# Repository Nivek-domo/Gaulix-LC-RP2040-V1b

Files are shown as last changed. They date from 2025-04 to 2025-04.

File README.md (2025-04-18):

Version : Bêta. Elle est opérationnelle, mais proposée à titre de tests pour ses acquéreurs, pour le moment …

Résumé du projet

Ce projet vise à concevoir une carte basée sur le RP2040 LoRa, inspirée du modèle Waveshare, mais optimisée pour des performances accrues et une meilleure stabilité. L’objectif est d’offrir une solution modulaire et performante pour des applications LoRa à faible coût.

Caractéristiques principales :

Microcontrôleur : RP2040 et mémoire additionnel
Module LoRa : Version optimisée avec un véritable étage radio, incluant un TCXO pour une meilleure stabilité en fréquence. Avec le Ebyte e22-900m30s
Puissance de sortie : Jusqu’à 30dBm (1W), pouvant être bridée à 27dBm (0,5W) pour rester dans la légalité.
Alimentation :
Entrée 5V via USB-C (H13)
Possibilité d’alimentation via batterie lithium (H14) pour une autonomie accrue.
Interfaces accessibles :
I2C pour capteurs divers
UART pour GPS ou autres modules de communication
SPI pour Ethernet (W5500) ou écrans e-paper
GPIO analogiques et numériques
Firmware : Compatible avec un firmware custom pour maximiser les performances et les options de configuration.
Options d’alimentation autonome :

Panneau solaire + régulateur de tension à 5 V.
Batterie lithium avec gestion de charge intégrée.
Options de connectivité réseau :

Connexion directe au smartphone via OTG USB-C
Extension réseau via module Ethernet W5500
Choix du module LoRa : E22-900M30S

Cette carte est idéale pour une installation en point haut et un usage longue durée sans maintenance fréquente. Son coût maîtrisé et sa modularité en font un choix optimal pour les expérimentateurs LoRa et les radioamateurs souhaitant un réseau performant et fiable.

Ses caractéristiques:

Microprocesseur	RP2040
Partie LoRa	
Module	Ebyte 850~930 MHz E22-900M30S
Puissance max	30 dBm
Sensibilité	-150 dBm
TCXO	Oui
Alimentation de la carte	
Par port USB-C	Oui
Directe	5 Volts (5,5 Volts Max) Bornier à Vis
Batterie	un élément lithium 2500mA/H Bornier à Vis

Connectivité

Wifi	Non
Bluetooth	Non
USB	Oui type C
UART 1	Disponible sur broche Dupont
UART 2	Disponible sur broche Dupont
I2C	Disponible sur broche Dupont
SPI	Disponible sur broche Dupont
GPIO Disponible	3 x entrée Analogique
2 x entrée ou sortie numérique
Ethernet	Compatible carte W5500 sur le bus SPI à ajouter.
Fonctionnalités

Alimentation	Entrée fixe 5 Volts // USB C
Gestion panneau solaire	Non
Gestion batterie	Chargeur simple élément
POE	En développement
Firmware

Meshtatic	Version Bêta officielle en cours	Custom

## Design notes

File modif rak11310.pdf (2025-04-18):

Fichier
scr/graphics/img/icon.xbm

#ifndef USERPREFS_HAS_SPLASH #define icon_width 50

#define icon_height 28

static uint8_t icon_bits[] = {
0x0A, 0x00, 0x00, 0x00, 0x00, 0x00, 0x00, 0x40, 0x00, 0x00, 0x00, 0x00, 0x00, 0x00, 0x01, 0x38, 0x00, 0xFC, 0xFF, 0x03, 0x00, 0x70, 0x00, 0xFE, 0xFF, 0xFF, 0x7F, 0x00, 0x08, 0x05, 0xFE, 0xFF, 0xFF, 0x7F, 0x00, 0x08, 0xC0, 0xFF, 0xDF, 0x80, 0x7F, 0x00, 0x00, 0x00, 0xF0, 0x00, 0x02, 0x00, 0x00, 0x30, 0x00, 0x00, 0x70, 0x0C, 0x00, 0x00, 0x40, 0x00, 0x00, 0x00, 0x12, 0x00, 0x00, 0x80, 0x18, 0x00, 0x00, 0x00, 0x00, 0x00, 0x00, 0x01, 0x00, 0x00, 0x40, 0x00, 0x00, 0x00, 0x03, 0x00, 0x00, 0x00, 0x00, 0x00, 0x00, 0x0F, 0x00, 0x00, 0x80, 0x01, 0x00, 0x80, 0xFF, 0x00, 0x00, 0x00, 0xFF, 0x00, 0x80, 0x1F, 0x1C, 0x00, 0x00, 0xFF, 0x00, 0x00, 0x3F, 0x00, 0x04, 0x80, 0xFF, 0x00, 0x00, 0xFF, 0x00, 0x00, 0x80, 0xFE, 0x00, 0x00, 0xFF, 0x01, 0x00, 0x40, 0xFE, 0x00, 0x00, 0xFE, 0x0F, 0x00, 0x20, 0xFE, 0x00, 0x00, 0xFC, 0x0F, 0xFA, 0x01, 0xFE, 0x00, 0x00, 0xF8, 0x3F, 0x00, 0x00, 0xFE, 0x00, 0x00, 0xE0, 0xFF, 0x01, 0x00, 0xFE, 0x00, 0x00, 0xC0, 0xFF, 0x1F, 0xC0, 0xFF, 0x00, 0x00, 0x00, 0xFE, 0xFF, 0xFF, 0xFF, 0x00, 0x00, 0x00, 0xE0, 0xFF, 0xFF, 0x7F, 0x00, 0x00, 0x00, 0x00, 0xFC, 0xFF, 0x03, 0x00, 0x00, 0x00, 0x00, 0x00, 0x00, 0x00, 0x00, 0x00, 0x00, 0x00, 0x00, 0x00, 0x00, 0x00, };
#endif

scr/graphics/Screen.cpp

ligne 58

#if HAS_ETHERNET

#include "mesh/eth/ethClient.h" #endif

ligne 169
display->setFont(FONT_MEDIUM); display->setTextAlignment(TEXT_ALIGN_LEFT);
const char *title = "gaulix.fr";
display->drawString(x + getStringCenteredX(title), y + SCREEN_HEIGHT -FONT_HEIGHT_MEDIUM, title);
display->setFont(FONT_SMALL);

ligne 238

#if HAS_ETHERNET

static void drawEthernetFrame(OLEDDisplay *display, OLEDDisplayUiState *state, int16_t x, int16_t y)
{
display->setFont(FONT_SMALL);
display->setTextAlignment(TEXT_ALIGN_LEFT);

if (config.display.displaymode == meshtastic_Config_DisplayConfig_DisplayMode_INVERTED) { display->fillRect(0 + x, 0 + y, x + display->getWidth(), y + FONT_HEIGHT_SMALL); display->setColor(BLACK);
}

display->setColor(WHITE);
// Position verticale ajustée - commence plus haut int16_t y_offset = y + 2; // Réduit l'espace au-dessus // Alignement à gauche (x + petit offset)
int16_t x_offset = x + 2;
// Affichage non centré, aligné à gauche
display->drawString(x_offset, y_offset, "Ethernet Config:");
y_offset += FONT_HEIGHT_SMALL + 2; // Espacement légèrement réduit display->drawString(x_offset, y_offset, "IP: " + Ethernet.localIP().toString()); y_offset += FONT_HEIGHT_SMALL;
display->drawString(x_offset, y_offset, "Mask: " + Ethernet.subnetMask().toString()); y_offset += FONT_HEIGHT_SMALL;
display->drawString(x_offset, y_offset, "GW: " + Ethernet.gatewayIP().toString()); //y_offset += FONT_HEIGHT_SMALL;
//display->drawString(x_offset, y_offset, "DNS: " + Ethernet.dnsServerIP().toString()); }
#endif

ligne 453

snprintf(tempBuf, sizeof(tempBuf), "Critical fault #%d", error_code); display->drawString(0 + x, 0 + y, tempBuf);
display->setTextAlignment(TEXT_ALIGN_LEFT);
display->setFont(FONT_SMALL);
display->drawString(0 + x, FONT_HEIGHT_MEDIUM + y, "For help, please visit \ngaulix.fr"); }

ligne 2215

#if HAS_ETHERNET

if (Ethernet.hardwareStatus() != EthernetNoHardware) { normalFrames[numframes++] = drawEthernetFrame; }
#endif

scr/mesh/RadioInterface.cpp

ligne 48
RDEF(EU_868, 869.4f, 869.65f, 10, 0, 27, false, false, false), //RDEF(EU_868, 869.4f, 869.65f, 10, 0, 33, false, false, false),

scr/mesh/api/serverapi.h
ligne 47
//#if RAK_4631
#if defined(RAK_4631) || defined(RAK11310)

// Track wait time for RAK13800 Ethernet requests int32_t waitTime = 100;
#endif

scr/mesh/eth/ethClient.cpp
ligne 115

#ifdef RAK11310 // Initialize the SPI port ETH_SPI_PORT.setSCK(PIN_SPI0_SCK); ETH_SPI_PORT.setTX(PIN_SPI0_MOSI); ETH_SPI_PORT.setRX(PIN_SPI0_MISO); ETH_SPI_PORT.begin();

#endif

Ethernet.init(ETH_SPI_PORT, PIN_ETHERNET_SS);

uint8_t mac[6];

dans
scr/modules on ajoute 2 fichiers NivekRemoteModule.cpp

#include "NivekRemoteModule.h"

#include "configuration.h"

#include "MeshService.h"

bool NivekRemoteModule::wantPacket(const meshtastic_MeshPacket *p) {
if (MeshService::isTextPayload(p) && p->decoded.payload.size >= 12) { // 9 (Node ID) + 2 (Pin) + 1 (State)
// Récupérer l'ID du nœud en tant que chaîne de caractères
NodeNum nodeID = myNodeInfo.my_node_num;
char nodeIDStr[10]; // Stocke l'ID en tant que string
snprintf(nodeIDStr, sizeof(nodeIDStr), "%u", nodeID); // Convertir en string // Comparer les 9 premiers caractères avec l'ID du nœud
if (strncmp((char*)p->decoded.payload.bytes, nodeIDStr, 9) == 0) {
// Extraire le numéro de sortie (2 caractères après l'ID du nœud)
int pin = ((p->decoded.payload.bytes[9] - '0') * 10) + (p->decoded.payload.bytes[10] -'0');

// Vérifier que la valeur est bien entre 0 et 32
if (pin >= 0 && pin <= 32) {
// Extraire l'état de la sortie (dernier caractère)
bool state = (p->decoded.payload.bytes[11] == '1');

pinMode(pin, OUTPUT);

digitalWrite(pin, state);

// Affichage sur le port série pour debug Serial.print("Commande reçue pour Node "); Serial.print(nodeID);
Serial.print(" : Pin ");
Serial.print(pin);
Serial.print(" -> État "); Serial.println(state ? "ON" : "OFF");

return true;
}
}
}
return false;
}

et NivekRemoteModule.h

#pragma once

#include "SinglePortModule.h"

class NivekRemoteModule : public SinglePortModule
{
public:
NivekRemoteModule() : SinglePortModule("nivekRemote", meshtastic_PortNum_TEXT_MESSAGE_APP) {}

protected:
virtual bool wantPacket(const meshtastic_MeshPacket *p) override; };

et donc dans scr/modules/Modules.cpp
ligne 145

new NivekRemoteModule();
ligne 93

#include "modules/NivekRemoteModule.h"

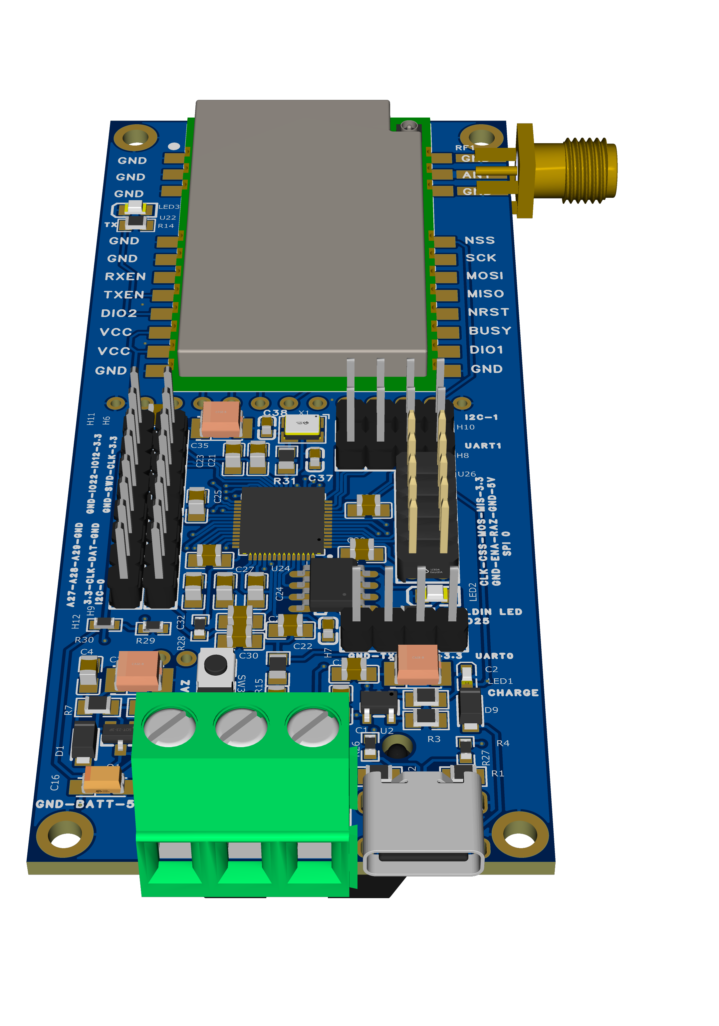
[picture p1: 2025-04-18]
3D_PCB1_2025-04-18.png

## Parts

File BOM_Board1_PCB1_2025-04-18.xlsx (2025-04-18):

No. | Quantity | Comment | Designator | Footprint | Value | Manufacturer Part | Manufacturer | Supplier Part | Supplier
1 | 2 | 1uF | C1,C4 | C0805 | 1uF | CL21B105KBFNNNE | SAMSUNG(三星) | C28323 | LCSC
2 | 3 | 100uF | C2,C3,C35 | CASE-B_3528 | 100uF | TAJB107K006RNJ | Kyocera AVX | C16133 | LCSC
3 | 15 | 100nF | C12,C15,C21,C22,C23,C24,C25,C26,C27,C28,C29,C30,C31,C32,C36 | C0805 | 100nF | CC0805KRX7R9BB104 | YAGEO(国巨) | C49678 | LCSC
4 | 1 | 10uF | C16 | CAP-SMD_L3.2-W1.6-RD-C7171 | 10uF | TAJA106K016RNJ | Kyocera AVX | C7171 | LCSC
5 | 1 | 1uF | C20 | C0603 | 1uF | CL10A105KO8NNNC | SAMSUNG(三星) | C1592 | LCSC
6 | 2 | 15pF | C37,C38 | C0603 | 15pF | CL10C150JB8NNNC | SAMSUNG(三星) | C1644 | LCSC
7 | 3 | MBR140SFT1G | D1,D9,D10 | SOD-123F_L2.8-W1.8-LS3.7-RD |  | MBR140SFT1G | onsemi(安森美) | C43381 | LCSC
8 | 6 | PZ254V-11-04P | H7,H8,H9,H10,H11,H12 | HDR-TH_4P-P2.54-V-M |  | PZ254V-11-04P | XFCN(兴飞) | C2691448 | LCSC
9 | 1 | KT-0603R | LED1 | LED0603-RD |  | KT-0603R | KENTO | C2286 | LCSC
10 | 1 | KT-0805G | LED2 | LED0805-R-RD |  | KT-0805G | KENTO | C2297 | LCSC
11 | 1 | KT-0805B | LED3 | LED0805-R-RD |  | KT-0805B | KENTO | C2293 | LCSC
12 | 1 | WJ500V-5.08-3P | P1 | CONN-TH_3P-P5.00_WJ500V-5.08-3P |  | WJ500V-5.08-3P | KANGNEX(康奈克斯电气) | C72334 | LCSC
13 | 1 | AO3401A | Q1 | SOT-23_L2.9-W1.3-P1.90-LS2.4-BR |  | AO3401A | AOS | C15127 | LCSC
14 | 4 | 4.7kΩ | R1,R2,R13,R14 | R0805 | 4.7kΩ | 0805W8F4701T5E | UNI-ROYAL(厚声) | C17673 | LCSC
15 | 1 | 2.7kΩ | R3 | R0805 | 2.7kΩ | 0805W8F2701T5E | UNI-ROYAL(厚声) | C17530 | LCSC
16 | 3 | 1kΩ | R4,R7,R31 | R0805 | 1kΩ | 0805W8F1001T5E | UNI-ROYAL(厚声) | C17513 | LCSC
17 | 2 | 10kΩ | R8,R15 | R0805 | 10kΩ | 0805W8F1002T5E | UNI-ROYAL(厚声) | C17414 | LCSC
18 | 2 | 27Ω | R26,R27 | R0603 | 27Ω | 0603WAF270JT5E | UNI-ROYAL(厚声) | C25190 | LCSC
19 | 1 | 200Ω | R28 | R0603 | 200Ω | 0603WAF2000T5E | UNI-ROYAL(厚声) | C8218 | LCSC
20 | 1 | 100kΩ | R29 | R0603 | 100kΩ | 0603WAF1003T5E | UNI-ROYAL(厚声) | C25803 | LCSC
21 | 1 | 200kΩ | R30 | R0603 | 200kΩ | 0603WAF2003T5E | UNI-ROYAL(厚声) | C25811 | LCSC
22 | 1 | BWSMA-KE-P001 | RF1 | SMA-SMD_BWSMA-KE-P001 |  | BWSMA-KE-P001 | BAT WIRELESS(蝙蝠无线) | C496550 | LCSC
23 | 2 | TSA343G00D-250J2 | SW3,SW4 | SW-SMD_L4.0-W2.9-P4.15-EH |  | TSA343G00D-250J2 | BRIGHT(博瑞泰) | C354947 | LCSC
24 | 1 | TP4054 | U2 | SOT-23-5_L2.9-W1.6-P0.95-LS2.8-BR |  | TP4054 | JSMSEMI(杰盛微) | C5381776 | LCSC
25 | 1 | E22-900M30S | U22 | WIRELM-SMD_E22-900M30S |  | E22-900M30S | EBYTE(亿佰特) | C411294 | LCSC
26 | 1 | RP2040 | U24 | LQFN-56_L7.0-W7.0-P0.4-EP |  | RP2040 | Raspberry Pi(树莓派) | C2040 | LCSC
27 | 1 | W25Q16JVSNIQ | U25 | SOP-8_L4.9-W3.9-P1.27-LS6.0-BL |  | W25Q16JVSNIQ | WINBOND(华邦) | qspi ss patte 56 sd0 | LCSC
28 | 1 | ZX-PZ2.54-2-5PZZ | U26 | HDR-TH_10P-P2.54-V-M-R2-C5-S2.54 |  | ZX-PZ2.54-2-5PZZ | Megastar(兆星) | C7501276 | LCSC
29 | 1 | AMS1117-3.3 | U27 | SOT-223-4_L6.5-W3.5-P2.30-LS7.0-BR |  | AMS1117-3.3 | UMW(友台半导体) | C347222 | LCSC
30 | 1 | 918-418K2023S40001 | USBC1 | USB-C-SMD_TYPE-C-USB-17 |  | 918-418K2023S40001 | 精拓金 | C167321 | LCSC
31 | 1 | 12MHz | X1 | OSC-SMD_4P-L3.2-W2.5-BL | 12MHz | XL2EL89COI-111YLC-12M | YXC(扬兴晶振) | C5280578 | LCSC

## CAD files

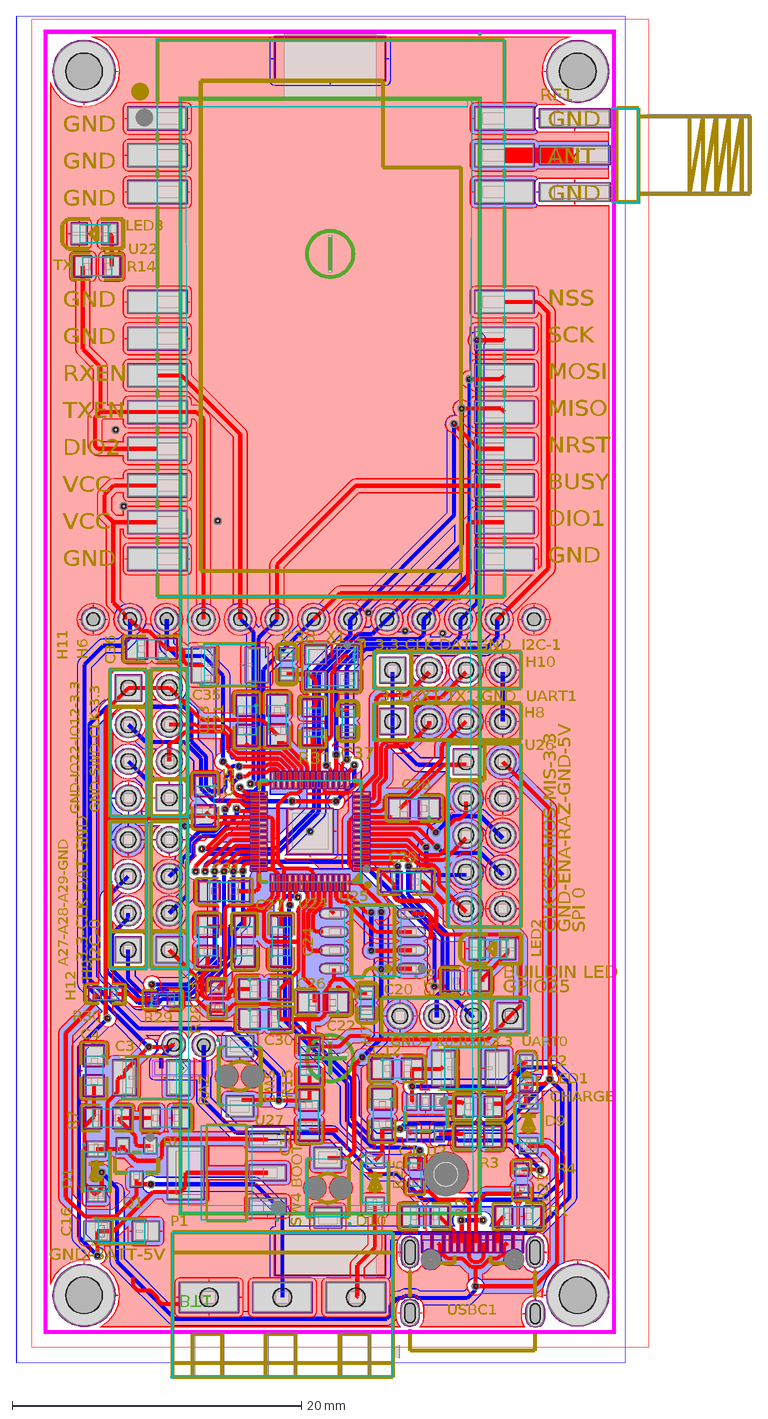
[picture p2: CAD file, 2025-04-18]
DXF_PCB1_2025-04-18_AutoCAD2007.dxf
BT1
GND
ANT
RXEN
TXEN
DIO2
VCC
NSS
SCK
MOSI
MISO
NRST
BUSY
DIO1
3.3-CLK-DAT-GND I2C-1
3.3-RX1-TX1-GND UART1
CLK-CSS-MOS-MIS-3.3
GND-ENA-RAZ-GND-5V
SPI 0
BUILDIN LED
GPIO25
GND-TX0-RX0-3.3 UART0
CHARGE
RAZ
BOOT
TX
GND-IO22-IO12-3.3
GND-SWD-CLK-3.3
3.3-CLK-DAT-GND
I2C-0
A27-A28-A29-GND
GND-BATT-5V
USBC1
R1
R2
D1
U2
D9
C1
C2
Q1
R7
R8
C3
C4
C12
LED2
R13
LED3
R14
C15
R15
R3
R4
LED1
C16
U22
C20
C21
C22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

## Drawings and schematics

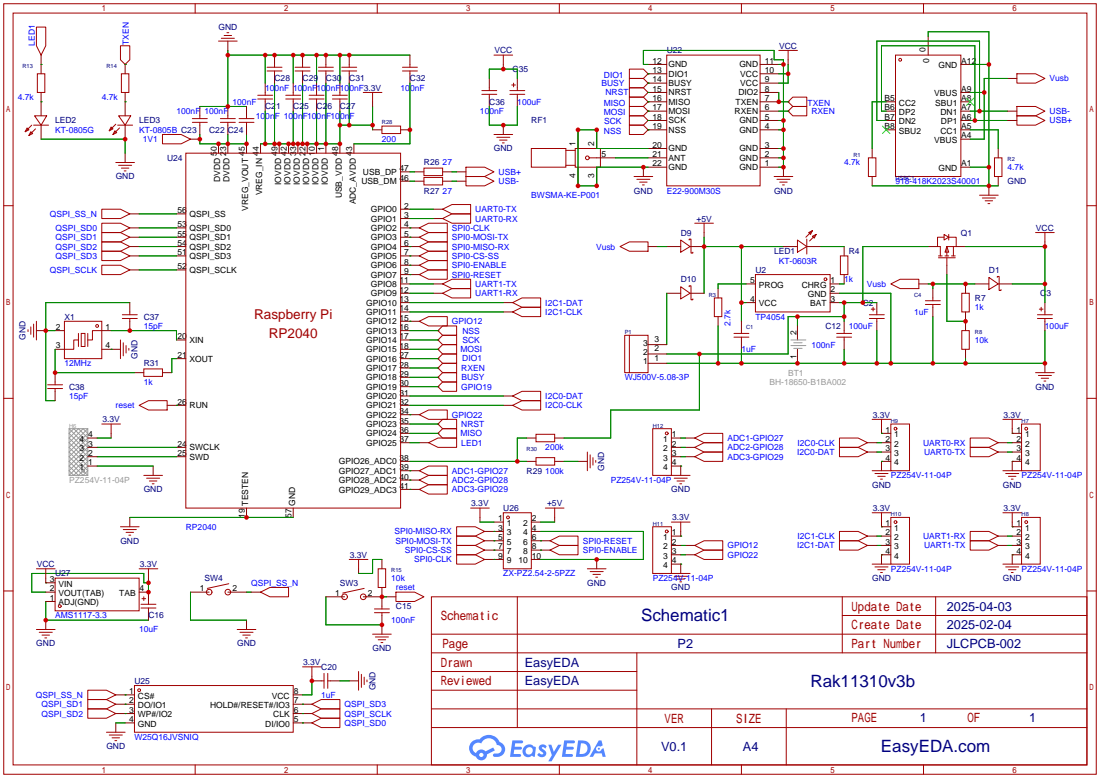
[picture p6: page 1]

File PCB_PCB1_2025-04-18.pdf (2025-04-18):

# GND

# GND

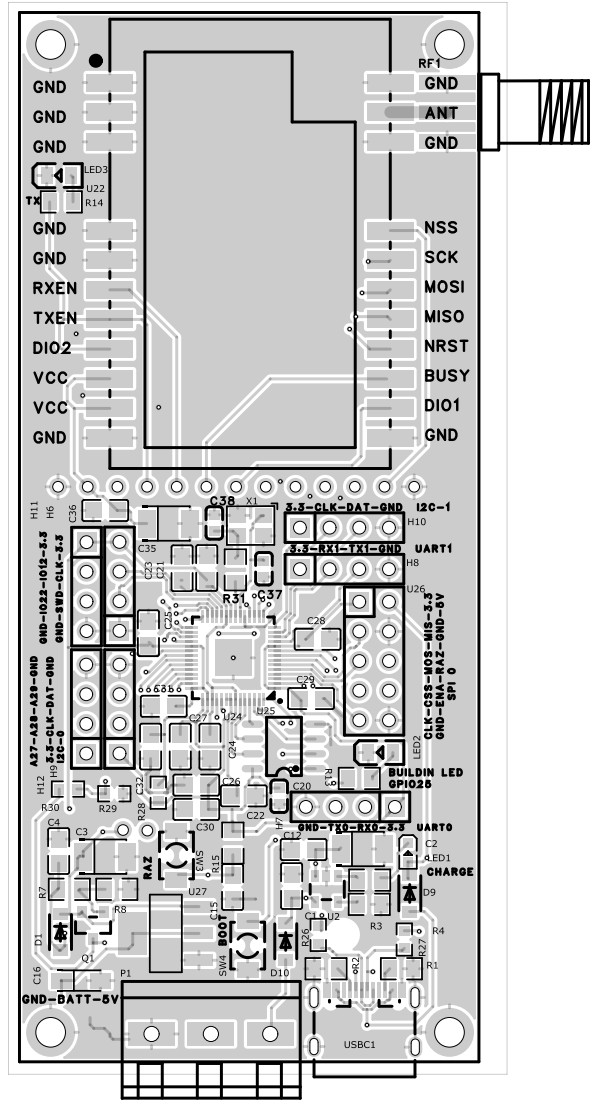
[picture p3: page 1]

3.3-RX1-TX1-GND UART1 CLK⁻CSS⁻MOS⁻MIS⁻³.3

GND-ENA-RAZ-GND-5V

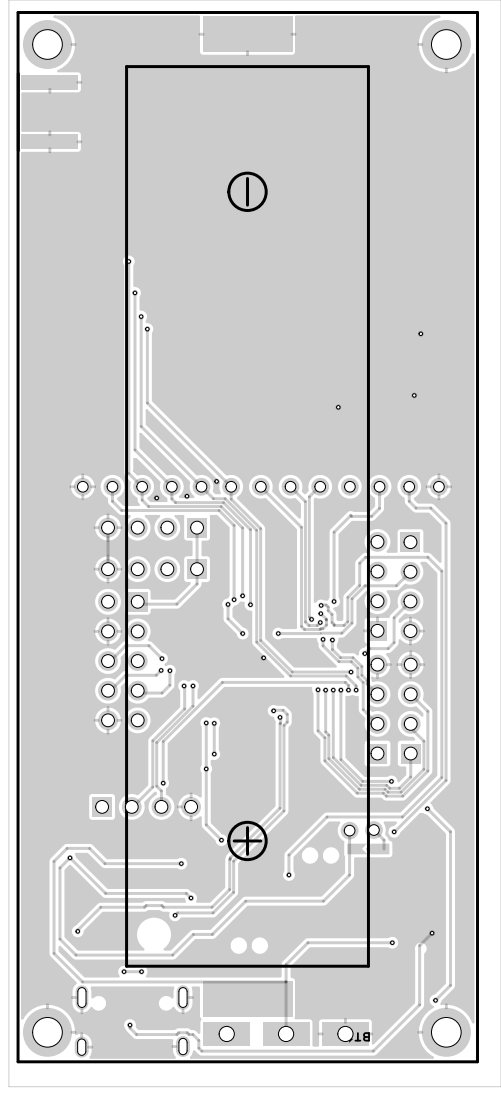
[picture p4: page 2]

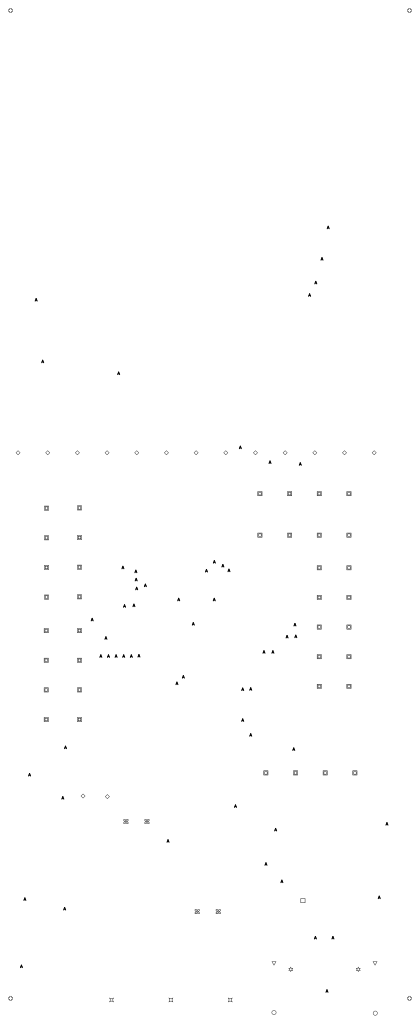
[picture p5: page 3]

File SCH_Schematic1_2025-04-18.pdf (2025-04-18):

# QSPI_SD3 51 DVDD ⁵⁰
